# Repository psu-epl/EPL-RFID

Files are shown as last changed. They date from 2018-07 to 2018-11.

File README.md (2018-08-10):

# EPL-RFID
RFID system for controlling access to EPL machines

This repo started as copies of two separate Capstone projects in 2018: the CS
backend Capstone called LUCCA (Lab Usage Controller for Centralized Administration)
and the ECE Capstone called EPL RFID Capstone Project.

Here are links to the previous repos:

### LUCCA:
#### Repo: https://github.com/LUCCA-Capstone/LUCCA
#### Wiki: https://github.com/LUCCA-Capstone/LUCCA/wiki

### EPL RFID:
#### Repo: https://github.com/Crimson89/RFID-Capstone
#### Wiki: https://github.com/Crimson89/RFID-Capstone/wiki

# Building ESP-IDF toolchain and environment
From a linux console type the following commands:   

git clone https://github.com/psu-epl/EPL-RFID.git  
cd EPL-RFID  
git submodule update --init  

Then follow "the Setting Up ESP-IDF" directions here: https://github.com/espressif/esp-idf  

This involves lots of building packages from source. You likely don't want to do this very many times.

make sure you edit your PATH variable in your ~/.bashrc to something similar to:

export IDF_PATH=~/path/to/submodule/esp-idf  
export PATH=$PATH:/home/chad/path/to/binaries/xtensa-esp32-elf/bin:/home/chad/path/to/binaries/crosstool-NG/builds/xtensa-esp32-elf/bin/

Bad things happen when you are following the wrong path...

Focus your chi using "echo $PATH"

Code to victory brave warrior!

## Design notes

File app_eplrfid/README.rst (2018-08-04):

app_eplrfid is based off the ESP-IDF template app.

Happy coding!

ESP-IDF template app
====================

This is a template application to be used with `Espressif IoT Development Framework`_ (ESP-IDF). 

Please check ESP-IDF docs for getting started instructions.

Code in this repository is Copyright (C) 2016 Espressif Systems, licensed under the Apache License 2.0 as described in the file LICENSE.

.. _Espressif IoT Development Framework: https://github.com/espressif/esp-idf

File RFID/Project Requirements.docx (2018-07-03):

ECE Capstone – Multiple Band RFID Scanner and Registration

Product Design Specification

1/1/2018

Capstone Team

Steven Bagdasarians

Julian Saunders

Dawit Amare

Josh Guenther

Background

The Electronics Prototyping Lab (EPL) is a Rapid Manufacturing lab in FAB 84-10. There is a lot of expensive and mildly complicated equipment in the lab. Some people who don’t know how to use the equipment come in and try to use the equipment and then end up either hurting the equipment or wasting time. We would like to be able to use hardware to control access of the equipment using our user database and training database. The overall process of use is: lab user uses their student ID or provided RFID tag to identify themselves and the system then checks a database to confirm they have been trained/checked out on the equipment and then gives some visual/auditory feedback and may deny them access to the equipment by prohibiting it from being powered up.

Functionality:

- Must read two different RFID bands (125 KHz & 13.5 MHz)
- Must communicate with other modules with Wifi
- Must run on embedded Linux environment
- Must incorporate a serial 2x30 LCD display
- Must display user information when badge is scanned
- Must include hdmi out, usb ports, digital pins, sd port
- Must be programmed with ip address, station id, unique id, etc
- Must maintain module identity/information after power down
- Should notify user if they have access or not (beeps, flashes, voice, etc)
- May utilize Bluetooth 3.0/4.0/BLE to communicate along with Wifi
- May have optional/customizable notification settings

Marketing Requirements:

- Must be usable by anyone / straightforward documentation
- Should be inexpensive to make
- Should only require keyboard and monitor to set up
- May be compatible with other databases

Performance:

- Must be easily programed and reprogrammable
- Must be easy to debug (displays ip address, station id, unique device id, etc)
- Should have a quick response time of no more than 1 second

Economic:

- Must be cheaper than commercial products

Energy:

- Must run off USB power (5v Supply)
- Should have protection from power spikes
- My have backup battery power if needed

Manufacturing:

- Must be easily reproduced.
- Must work for Raspberry Pi 0 W
- Must be Modular
- Should have custom designed PCB for final design
- Should have simple and inexpensive casing

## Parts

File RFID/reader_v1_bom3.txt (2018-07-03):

Partlist exported from C:/Users/Owner/Documents/eagle/Capstone_RFID/reader_v1.sch at 5/26/2018 2:22 PM

Qty Value                                 Package     Parts                        Description                                                                                                   
1   Red LED                               LED5MM      RED                          LED                                                                     
1   Green LED                             LED5MM      GREEN                        LED                                                                                                                         
1   1 Meg                                 R0805       R2                           RESISTOR, American symbol                                               
1   1.8k                                  R0805       R3                           RESISTOR, American symbol                                               
1   100                                   R0805       R11                          RESISTOR, American symbol                                               
4   100n                                  C0805       C12, C13, C16, C17           CAPACITOR, European symbol                                              
6   10k                                   R0805       R7, R8, R9, R12, R15, R18    RESISTOR, American symbol                                               
1   12V Zener                             Thru Hole   D1                           DIODE                                                                   
2   15k                                   R0805       R10, R19                     RESISTOR, American symbol                                               
1   16MHz                                 CRYSTAL     Y1                           16MHz Crystal                                                           
1   1N5824 (20-40V, 5A Schottkey)         Thru Hole   D2                           Schottky Diode                                                          
2   1k                                    R0805       R13, R14                     RESISTOR, American symbol                                               
7   1n                                    C0805       C4, C6, C7, C8, C9, C10, C11 CAPACITOR, European symbol                                              
1   2.2n                                  C0805       C5                           CAPACITOR, European symbol                                              
1   2.7k                                  R0805       R5                           RESISTOR, American symbol                                               
2   220                                   R0805       R16, R17                     RESISTOR, American symbol                                               
1   220u                                  Polarized   C20                          POLARIZED CAPACITOR, American symbol                                    
2   22p                                   C0805       C14, C15                     CAPACITOR, European symbol                                              
1   328P                                  DIP28       U1                           Atmel 328P                                                              
1   33u                                   Thru Hole   L1                           INDUCTOR, American symbol                                               
1   47k                                   R0805       R4                           RESISTOR, American symbol                                               
1   680u                                  Polarized   C19                          POLARIZED CAPACITOR, American symbol                                    
1   82k                                   R0805       R6                           RESISTOR, American symbol                                               
1   860k                                  R0805       R1                           RESISTOR, American symbol                                               
1   BUZZER (=<3.3V)                       BUZZER-12MM BUZZER                       Buzzer                                                                  
2   LF353N                                DIL08       LF353_1, LF353_2             OP AMP                                                                  
1   LM2596T                               T05D        LM2596                       SIMPLE SWITCHER® Power Converter 150 kHz 3A Step-Down Voltage Regulator 
1   2x20 Female Header		 	  2X20        J1                           Raspberry Pi GPIO Header

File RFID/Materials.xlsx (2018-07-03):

Date | Part | Quantity | Location | Price/unit | Price (Total) | Notes
2018-01-18 | RPi 3 - 16GB Noobs | 1 | EPL | $50.00 | $50.00
2018-02-02 | 28 Guage Magnetic Wire | Spool | EPL |  | #VALUE!
2018-02-02 | 100 Ohm Resitor | 1 | EPL | $0.10 | $0.10
2018-02-02 | 1.8 nF Cap | 1 | EPL | $0.25 | $0.25
2018-02-22 | MCP3201 (ADC) | 1 | EPL | $3.00 | $3.00
2018-03-08 | LM358 (Op Amp) | 3 | EPL | $0.60 | $1.80
2108-03-28 | Resistors | 13 | EPL | $0.10 | $1.30
2018-03-28 | Capacitors | 6 | EPL | $0.25 | $1.50
2018-04-01 | LF353 (Op Amp) | 5 | EPL | $0.75 | $3.75
2018-04-01 | NE5532 (Op Amp) | 3 | EPL | $1.25 | $3.75
2018-04-19 | LM555 Timer | 2 | EPL | $0.50 | $1.00
2018-04-26 | 74HC74 Dual D Flip Flop | 1 | EPL | $0.50 | $0.50
2018-05-10 | Atmega328P | 2 | EPL | $5.00 | $10.00
2018-05-19 | Copper Board (4x6) Single Sided | 1 | EPL | $4.00 | $4.00
2018-05-19 | SMD Caps | 11 | EPL | $0.10 | $1.10
2018-05-19 | SMD Resistors | 14 | EPL | $0.10 | $1.40
2018-05-20 | USB A to B | 1 | EPL | $3.00 | $3.00
2018-06-06 | USB micro | 1 | EPL | $3.00 | $3.00
2018-06-06 | 2x3 Protoboard | 1 | EPL | $3.00 | $3.00
2018-06-07 | HDMI Cable | 1 | EPL | $5.00 | $5.00
2018-06-07 | 12V 2A Power Supply | 2 | EPL |  | $0.00

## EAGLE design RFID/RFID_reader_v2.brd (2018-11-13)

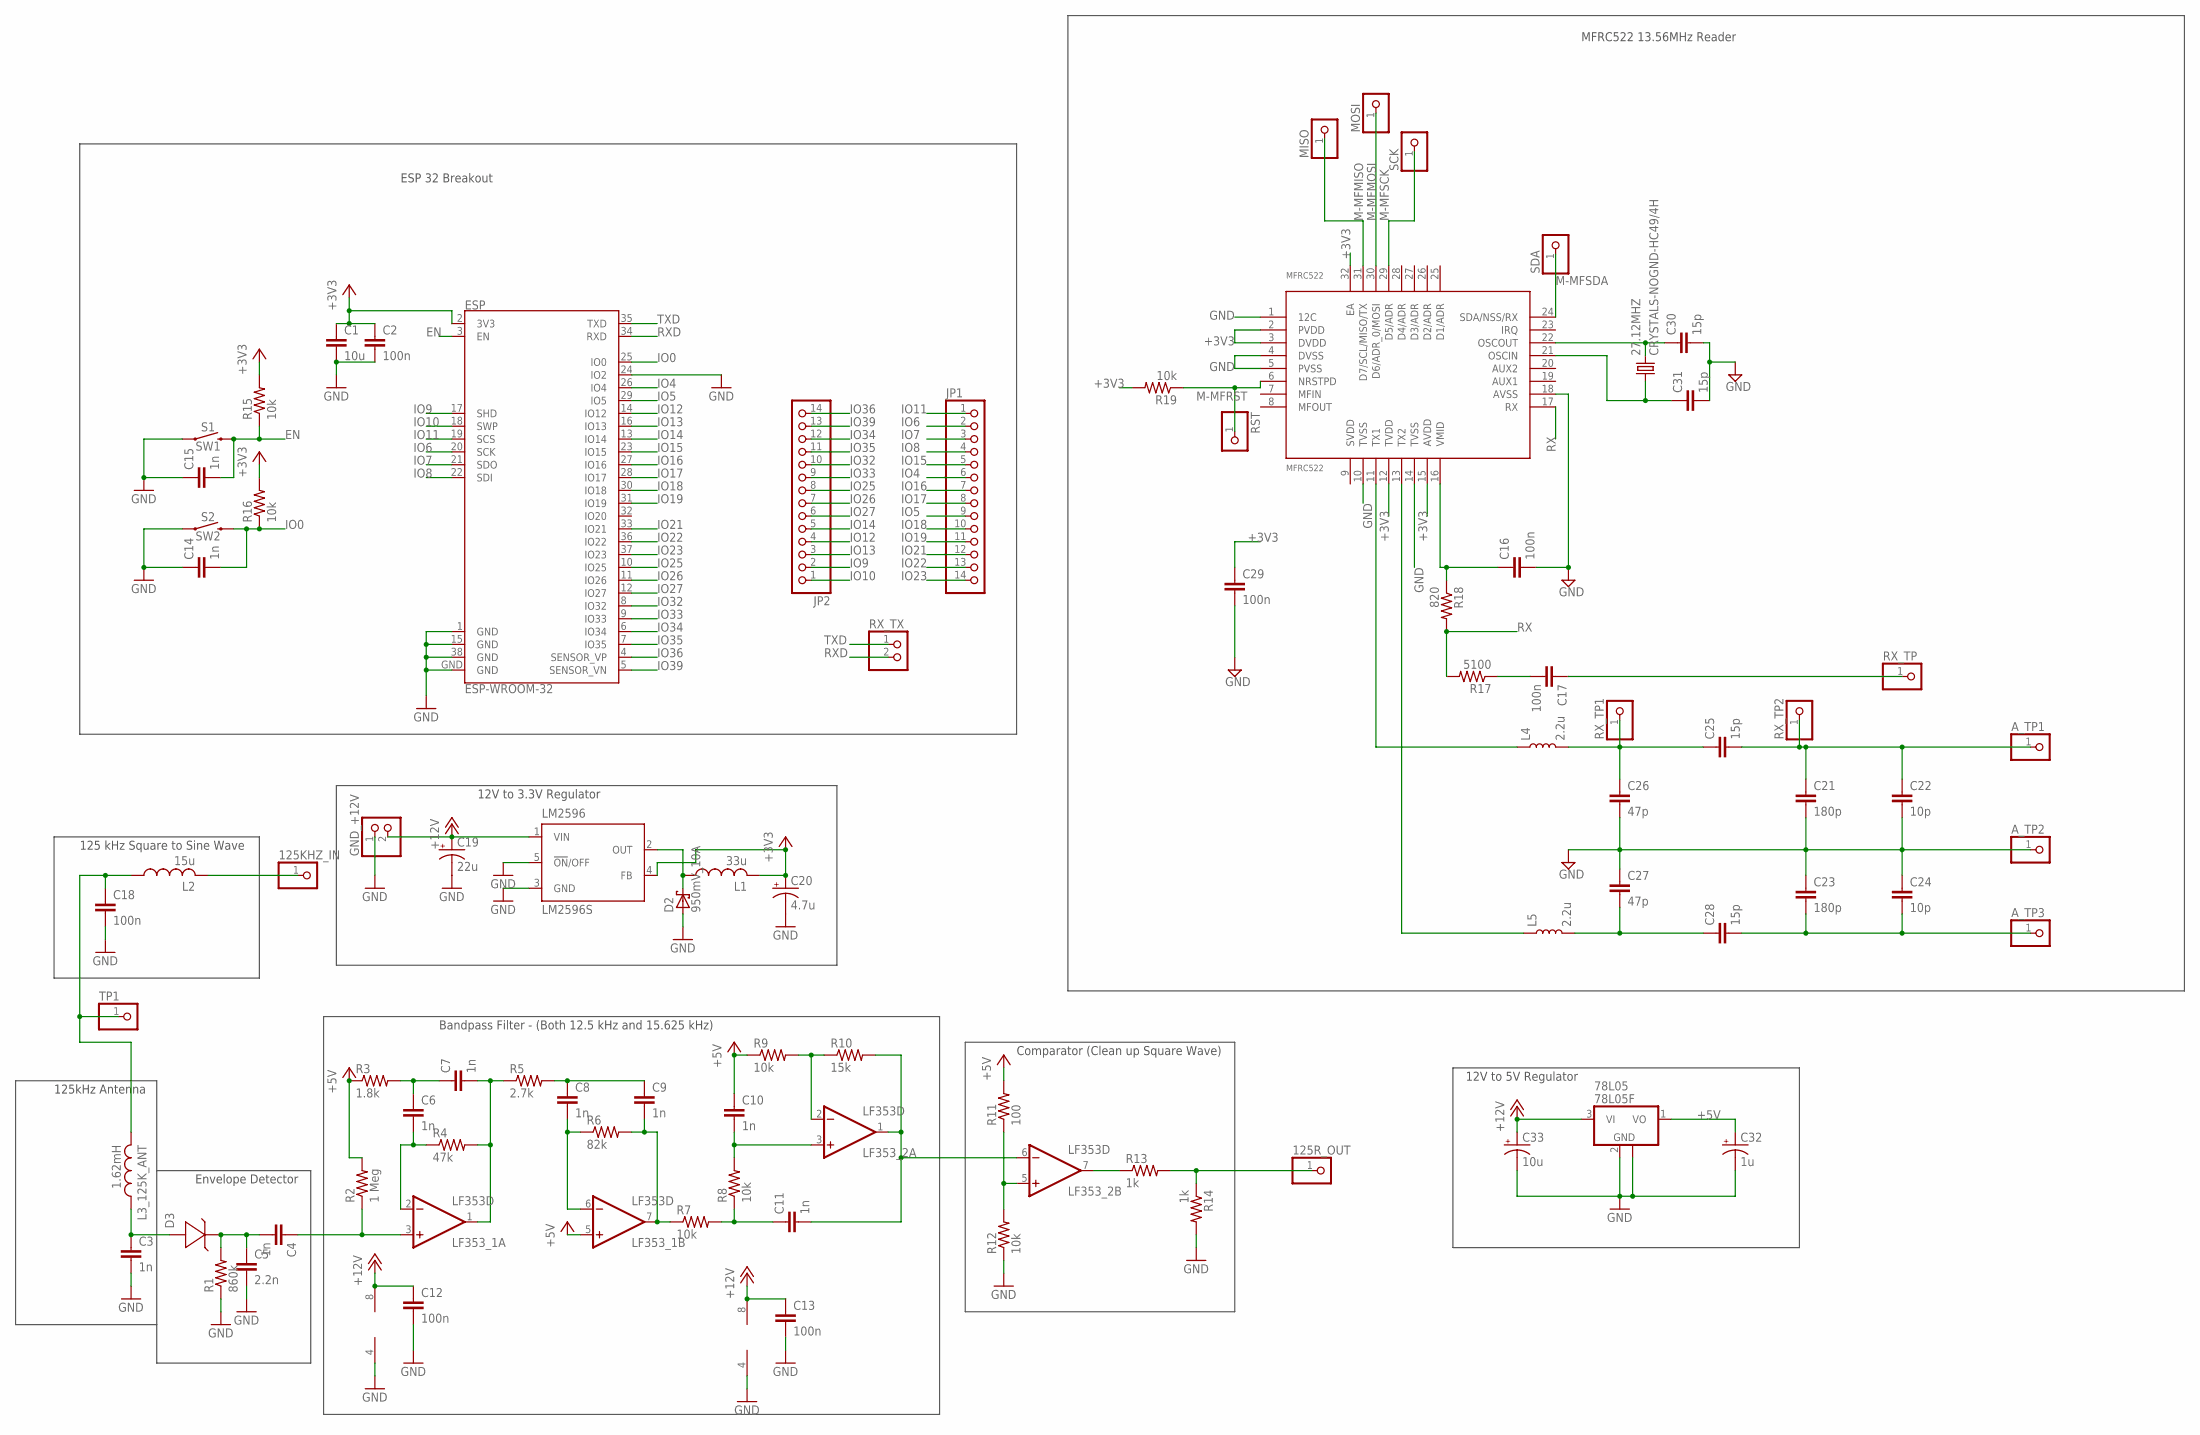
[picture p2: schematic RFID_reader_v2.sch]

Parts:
27.12MHZ: CRYSTALS-NOGND-HC49/4H; HC49
78L05: 78L05F; SOT89
125KHZ_IN, 125R_OUT: PINHD-1X1; 1X01
A_TP1, A_TP2, A_TP3: PINHD-1X1; 1X01
C1: 10u; C0805
C2, C12, C13, C18: 100n; C0805
C3, C4, C6, C7, C8, C9, C10, C11, C14, C15: 1n; C0805
C5: 2.2n; C0805
C16, C17, C29: 100n; C0603
C19: 22u; SANYO-OSCON_SMD_B6
C20: 4.7u; SMC_C
C21, C23: 180p; C0603
C22, C24: 10p; C0603
C25, C28, C30, C31: 15p; C0603
C26, C27: 47p; C0603
C32: 1u; SMC_A
C33: 10u; SMC_C
D2: 950mV_10A; SMC
D3: ZENER; SOD123
ESP: ESP-WROOM-32
GND_+12V: PINHD-1X2; 1X02
JP1, JP2: PINHD-1X14; 1X14
L1: 33u; 0207/10
L2: 15u; L2012C
L3_125K_ANT: 1.62mH; 0207/10
L4, L5: 2.2u; 0603
LF353_1, LF353_2: LF353D; SO08
LM2596: LM2596S; TO263-5
MFRC522: MFRC522; MFR522
MISO: PINHD-1X1; 1X01
MOSI: PINHD-1X1; 1X01
R1: 860k; R0805
R2: 1 Meg; R0805
R3: 1.8k; R0805
R4: 47k; R0805
R5: 2.7k; R0805
R6: 82k; R0805
R7, R8, R9, R12, R15, R16: 10k; R0805
R10: 15k; R0805
R11: 100; R0805
R13, R14: 1k; R0805
R17: 5100; R0603
R18: 820; R0603
R19: 10k; R0603
RST: PINHD-1X1; 1X01
RX_TP, RX_TP1, RX_TP2: PINHD-1X1; 1X01
RX_TX: PINHD-1X2; 1X02
S1: SW1; TACTILE_SWITCH_SMD_6.0X3.5MM
S2: SW2; TACTILE_SWITCH_SMD_6.0X3.5MM
SCK: PINHD-1X1; 1X01
SDA: PINHD-1X1; 1X01
TP1: PINHD-1X1; 1X01

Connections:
+3V3: C1.1, C2.1, C20.+, C29.1, ESP.2 (3V3), L1.2, LM2596.4 (FB), MFRC522.2 (PVDD), MFRC522.3 (DVDD), MFRC522.12 (TVDD), MFRC522.15 (AVDD), MFRC522.32 (EA), R15.2, R16.2, R19.2
+5V: 78L05.1 (VO), C10.1, C32.+, LF353_1.5 (+IN), R2.2, R3.1, R9.1, R11.2
+12V: 78L05.3 (VI), C12.1, C13.1, C19.+, C33.+, GND_+12V.2, LF353_1.8 (V+), LF353_2.8 (V+), LM2596.1 (VIN)
EN: C15.2, ESP.3 (EN), R15.1, S1.2
GND: 78L05.2 (GND), 78L05.2@1 (GND), A_TP2.1, C1.2, C2.2, C3.2, C5.2, C12.2, C13.2, C14.1, C15.1, C16.2, C18.2, C19.-, C20.-, C21.2, C22.2, C23.1, C24.1, C26.2, C27.1, C29.2, C30.2, C31.2, C32.-, C33.-, D2.A, ESP.1 (GND), ESP.15 (GND), ESP.24 (IO2), ESP.38 (GND), ESP.GND, GND_+12V.1, LF353_1.4 (V-), LF353_2.4 (V-), LM2596.3 (GND), LM2596.5 (!ON!/OFF), MFRC522.1 (12C), MFRC522.4 (DVSS), MFRC522.5 (PVSS), MFRC522.10 (TVSS), MFRC522.14 (TVSS), MFRC522.18 (AVSS), R1.1, R12.1, R14.2, S1.1, S2.1
IO0: C14.2, ESP.25 (IO0), R16.1, S2.2
IO4: ESP.26 (IO4), JP1.6
IO5: ESP.29 (IO5), JP1.9
IO6: ESP.20 (SCK), JP1.2
IO7: ESP.21 (SDO), JP1.3
IO8: ESP.22 (SDI), JP1.4
IO9: ESP.17 (SHD), JP2.2
IO10: ESP.18 (SWP), JP2.1
IO11: ESP.19 (SCS), JP1.1
IO12: ESP.14 (IO12), JP2.4
IO13: ESP.16 (IO13), JP2.3
IO14: ESP.13 (IO14), JP2.5
IO15: ESP.23 (IO15), JP1.5
IO16: ESP.27 (IO16), JP1.7
IO17: ESP.28 (IO17), JP1.8
IO18: ESP.30 (IO18), JP1.10
IO19: ESP.31 (IO19), JP1.11
IO21: ESP.33 (IO21), JP1.12
IO22: ESP.36 (IO22), JP1.13
IO23: ESP.37 (IO23), JP1.14
IO25: ESP.10 (IO25), JP2.8
IO26: ESP.11 (IO26), JP2.7
IO27: ESP.12 (IO27), JP2.6
IO32: ESP.8 (IO32), JP2.10
IO33: ESP.9 (IO33), JP2.9
IO34: ESP.6 (IO34), JP2.12
IO35: ESP.7 (IO35), JP2.11
IO36: ESP.4 (SENSOR_VP), JP2.14
IO39: ESP.5 (SENSOR_VN), JP2.13
M-MFMISO: MFRC522.31 (D7/SCL/MISO/TX), MISO.1
M-MFMOSI: MFRC522.30 (D6/ADR_0/MOSI), MOSI.1
M-MFRST: MFRC522.6 (NRSTPD), R19.1, RST.1
M-MFSCK: MFRC522.29 (D5/ADR), SCK.1
M-MFSDA: MFRC522.24 (SDA/NSS/RX), SDA.1
unnamed: C4.2, C5.1, D3.C (-), R1.2
unnamed: C4.1, LF353_1.3 (+IN), R2.1
unnamed: D2.C, L1.1, LM2596.2 (OUT)
unnamed: C3.1, D3.A (+), L3_125K_ANT.1
unnamed: 125KHZ_IN.1, L2.2
unnamed: C6.1, C7.1, R3.2
unnamed: C6.2, LF353_1.2 (-IN), R4.1
unnamed: C8.1, C9.1, R5.2
unnamed: C7.2, LF353_1.1 (OUT), R4.2, R5.1
unnamed: C8.2, LF353_1.6 (-IN), R6.1
unnamed: C9.2, LF353_1.7 (OUT), R6.2, R7.1
unnamed: C11.1, R7.2, R8.1
unnamed: C10.2, LF353_2.3 (+IN), R8.2
unnamed: C17.2, R17.1
unnamed: LF353_2.2 (-IN), R9.2, R10.1
unnamed: C11.2, LF353_2.1 (OUT), LF353_2.6 (-IN), R10.2
unnamed: C18.1, L2.1, L3_125K_ANT.2, TP1.1
unnamed: LF353_2.5 (+IN), R11.1, R12.2
unnamed: LF353_2.7 (OUT), R13.1
unnamed: 125R_OUT.1, R13.2, R14.1
unnamed: C27.2, C28.1, L5.2
unnamed: C25.1, C26.1, L4.2, RX_TP1.1
unnamed: C17.1, RX_TP.1
unnamed: A_TP1.1, C21.1, C22.1, C25.2, RX_TP2.1
unnamed: A_TP3.1, C23.2, C24.2, C28.2
OSCIN: 27.12MHZ.1, C31.1, MFRC522.21 (OSCIN)
OSCOUT: 27.12MHZ.2, C30.1, MFRC522.22 (OSCOUT)
RX: MFRC522.17 (RX), R17.2, R18.2
RXD: ESP.34 (RXD), RX_TX.2
TX1: L4.1, MFRC522.11 (TX1)
TX2: L5.1, MFRC522.13 (TX2)
TXD: ESP.35 (TXD), RX_TX.1
VMID: C16.1, MFRC522.16 (VMID), R18.1

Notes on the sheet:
Envelope Detector
Bandpass Filter - (Both 12.5 kHz and 15.625 kHz)
Comparator (Clean up Square Wave)
125kHz Antenna
125 kHz Square to Sine Wave
12V to 5V Regulator
12V to 3.3V Regulator
ESP 32 Breakout
MFRC522 13.56MHz Reader

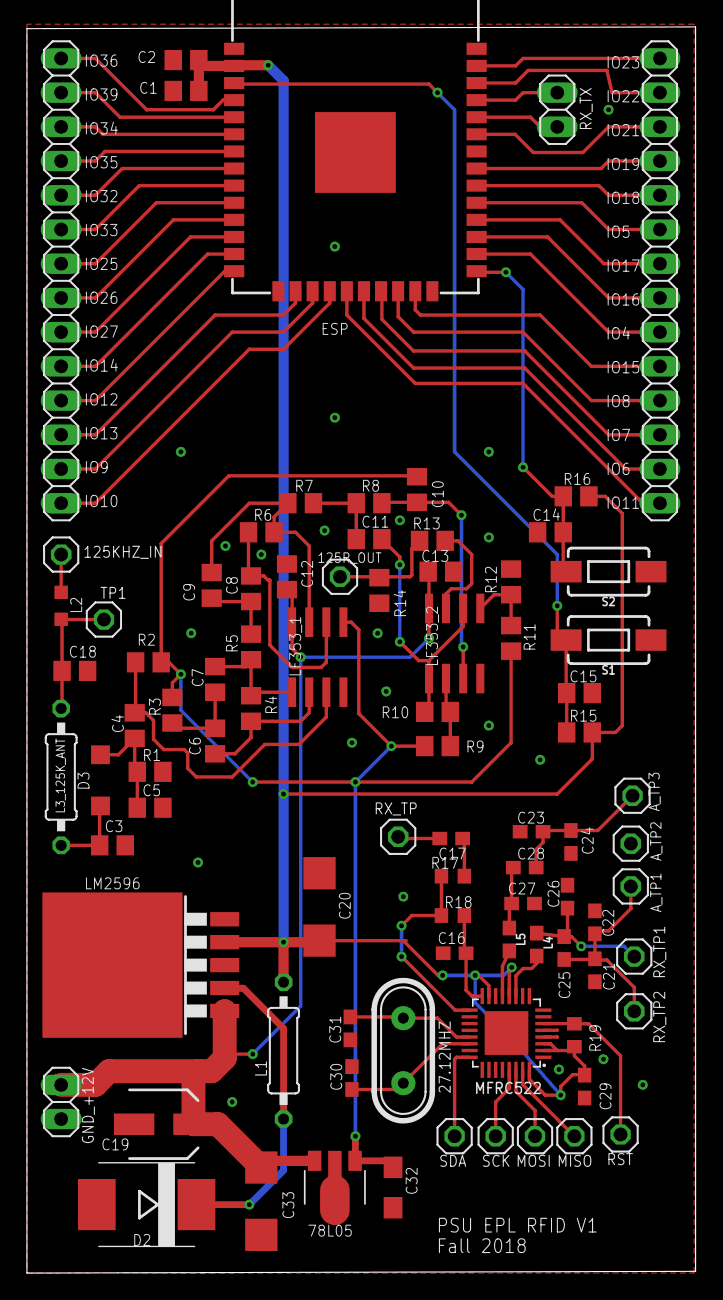
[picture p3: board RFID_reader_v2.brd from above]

Board: 2 copper layers, 49.6 x 92.5 mm, 86 parts (0 on the bottom side), 72 nets.

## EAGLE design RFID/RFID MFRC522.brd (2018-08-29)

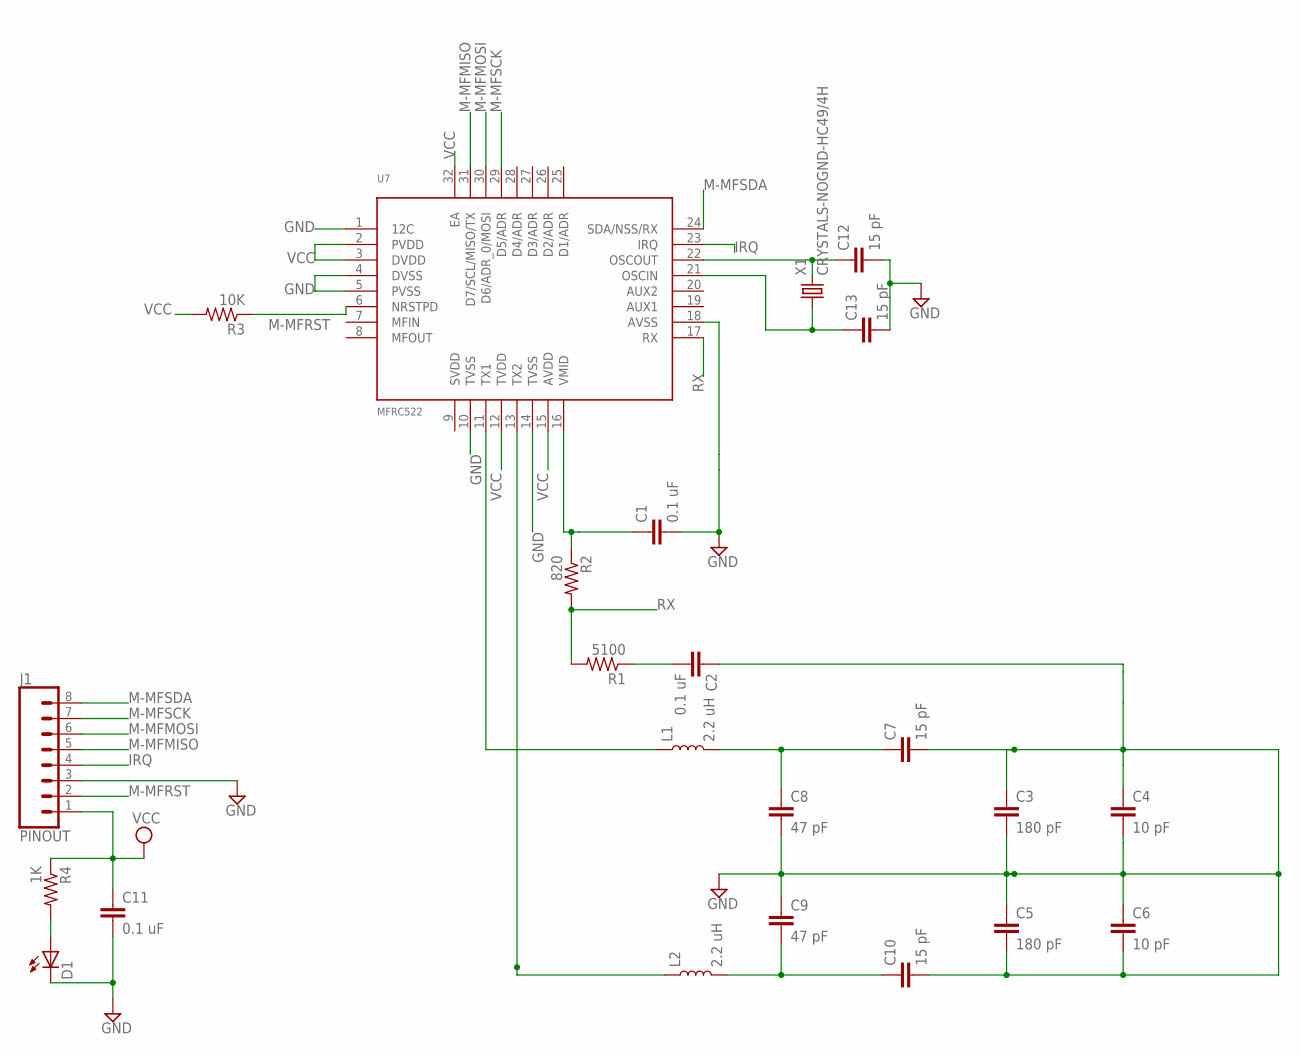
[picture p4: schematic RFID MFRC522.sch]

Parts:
C1, C2, C11: 0.1 uF; C0603
C3, C5: 180 pF; C0603
C4, C6: 10 pF; C0603
C7, C10, C12, C13: 15 pF; C0603
C8, C9: 47 pF; C0603
D1: LED; C1210
J1: PINOUT; 1X08_NO_SILK
L1, L2: 2.2 uH; 0603
R1: 5100; R0603
R2: 820; R0603
R3: 10K; R0603
R4: 1K; R0603
U7: MFRC522; MFR522
X1: CRYSTALS-NOGND-HC49/4H; HC49

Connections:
GND: C1.2, C2.1, C3.1, C3.2, C4.1, C4.2, C5.1, C5.2, C6.1, C6.2, C7.2, C8.2, C9.1, C10.2, C11.2, C12.2, C13.2, D1.C, J1.3, U7.1 (12C), U7.4 (DVSS), U7.5 (PVSS), U7.10 (TVSS), U7.14 (TVSS), U7.18 (AVSS)
IRQ: J1.4, U7.23 (IRQ)
M-MFMISO: J1.5, U7.31 (D7/SCL/MISO/TX)
M-MFMOSI: J1.6, U7.30 (D6/ADR_0/MOSI)
M-MFRST: J1.2, R3.1, U7.6 (NRSTPD)
M-MFSCK: J1.7, U7.29 (D5/ADR)
M-MFSDA: J1.8, U7.24 (SDA/NSS/RX)
unnamed: D1.A, R4.2
unnamed: C2.2, R1.1
unnamed: C9.2, C10.1, L2.2
unnamed: C7.1, C8.1, L1.2
OSCIN: C13.1, U7.21 (OSCIN), X1.1
OSCOUT: C12.1, U7.22 (OSCOUT), X1.2
RX: R1.2, R2.2, U7.17 (RX)
TX1: L1.1, U7.11 (TX1)
TX2: L2.1, U7.13 (TX2)
VCC: C11.1, J1.1, R3.2, R4.1, U7.2 (PVDD), U7.3 (DVDD), U7.12 (TVDD), U7.15 (AVDD), U7.32 (EA)
VMID: C1.1, R2.1, U7.16 (VMID)

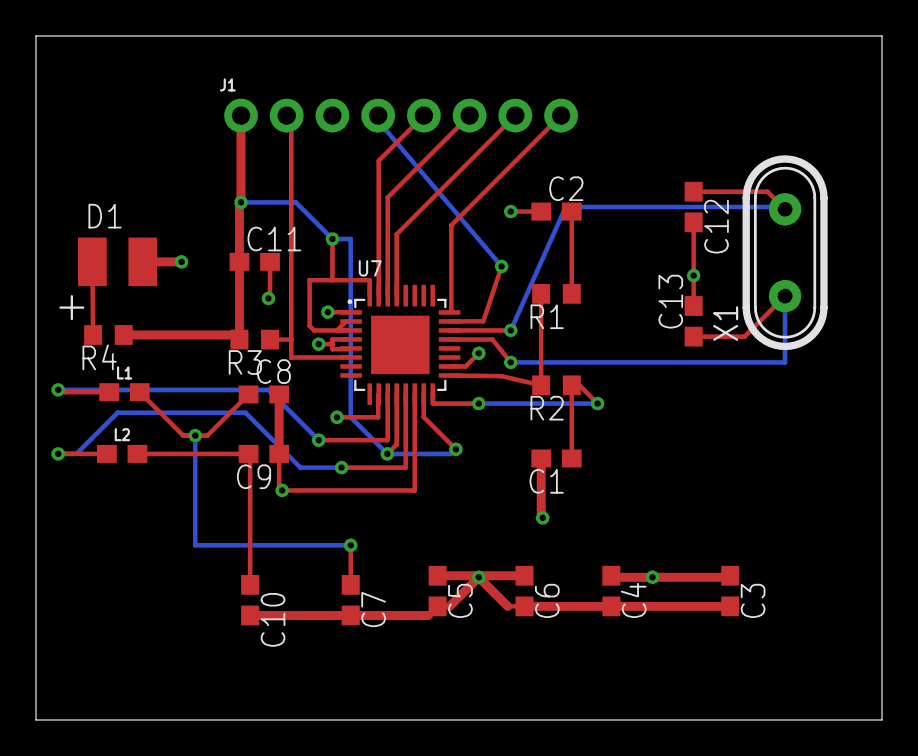
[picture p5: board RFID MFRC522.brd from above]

Board: 2 copper layers, 47.0 x 38.0 mm, 23 parts (0 on the bottom side), 18 nets.

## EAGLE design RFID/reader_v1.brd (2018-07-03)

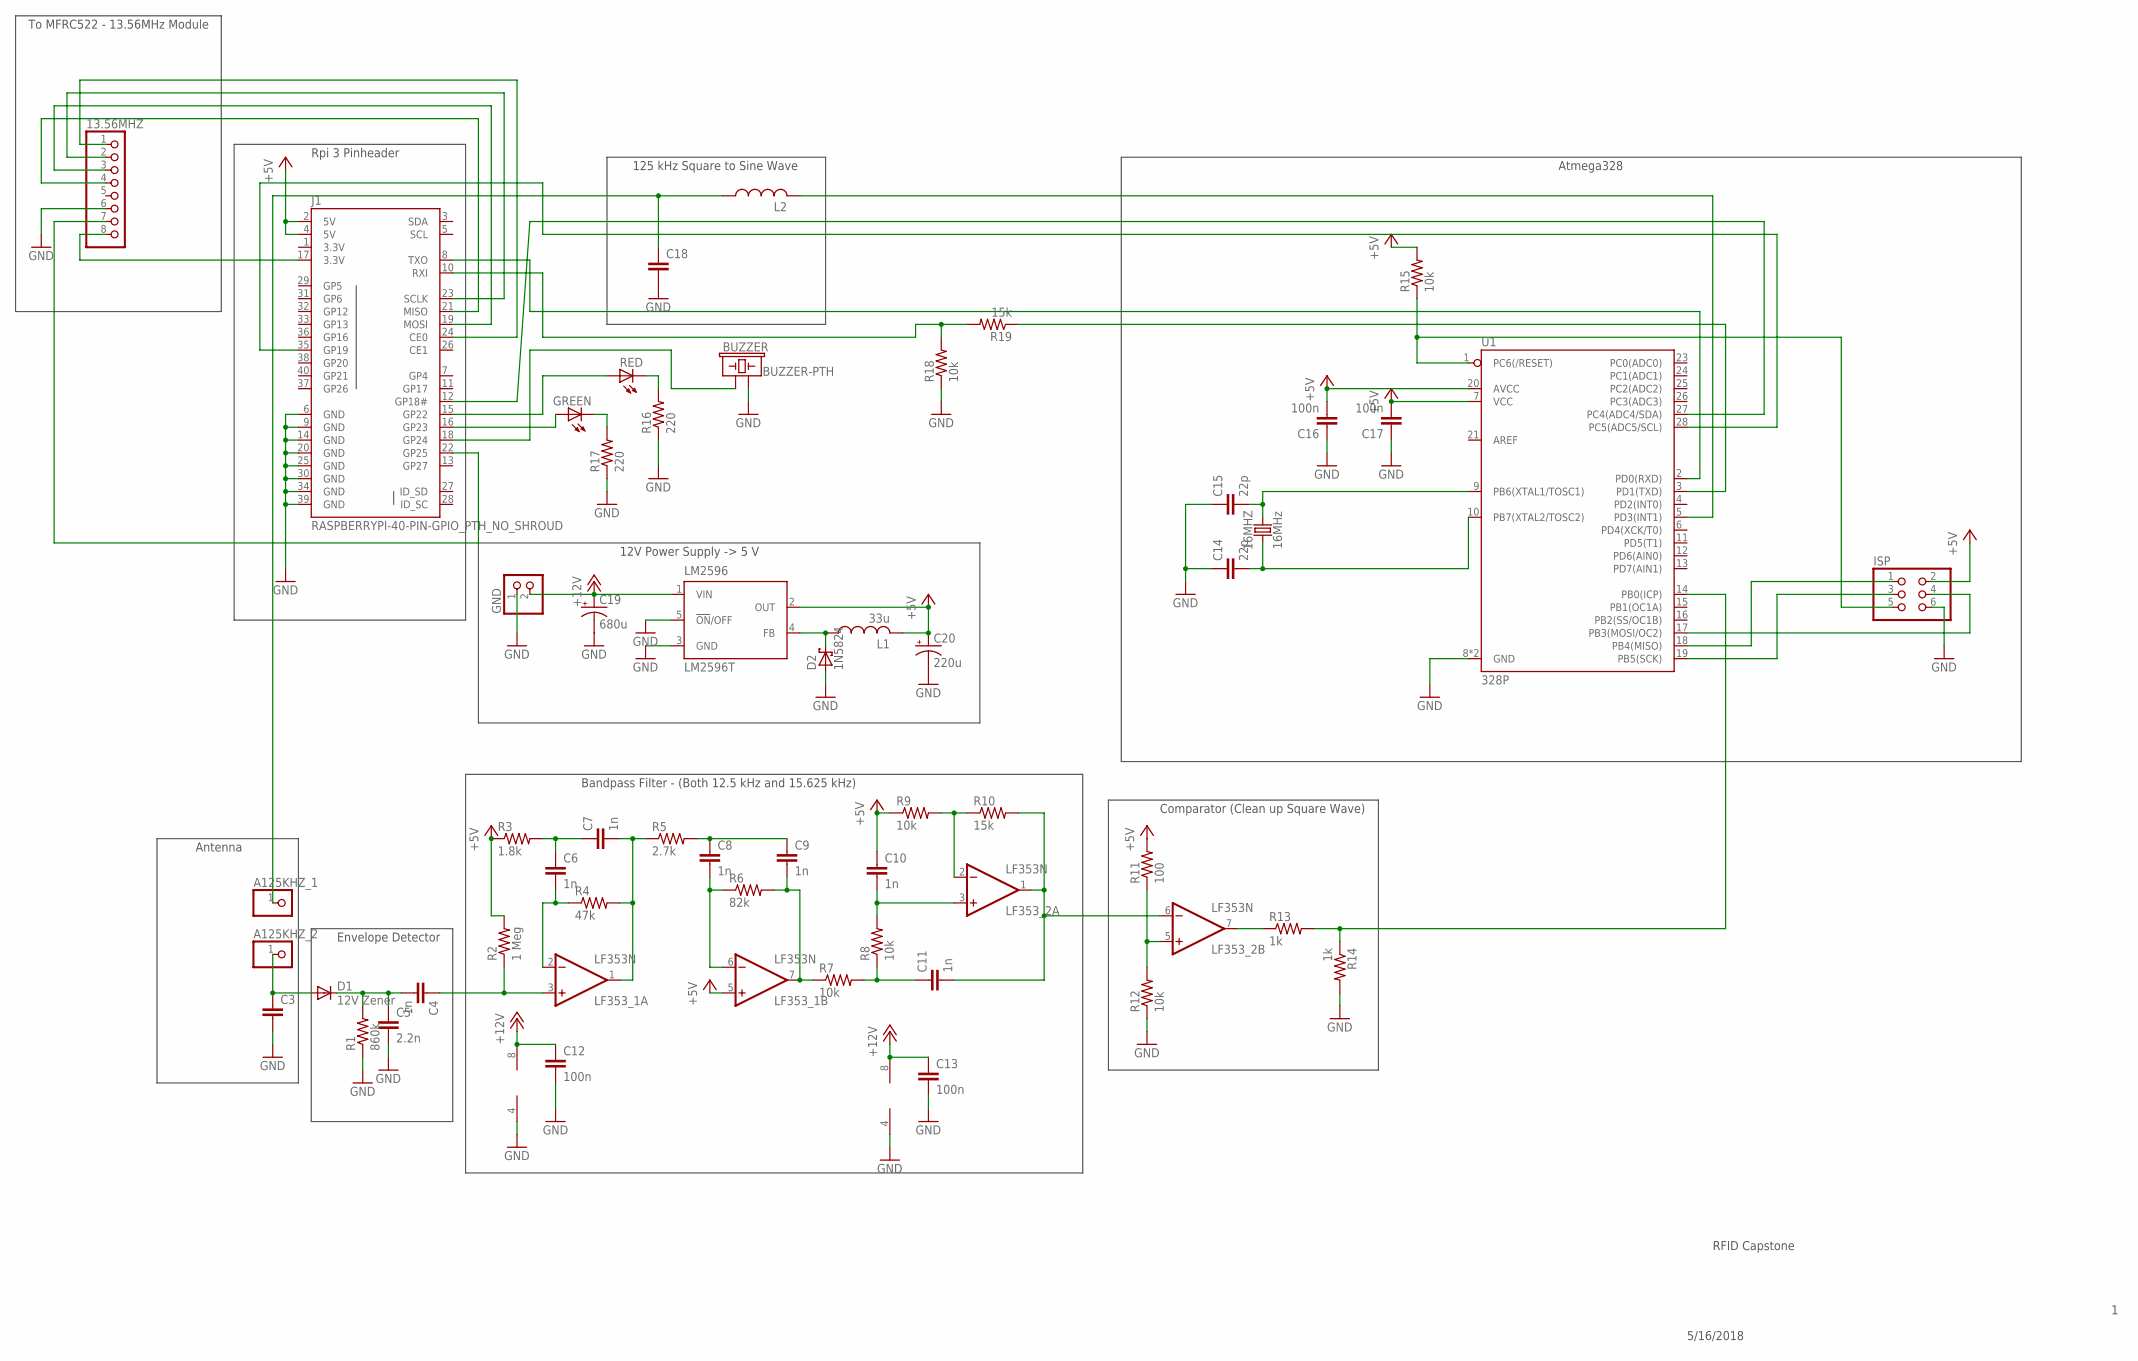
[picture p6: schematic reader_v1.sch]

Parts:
13.56MHZ: PINHD-1X8; 1X08
16MHZ: 16MHz; HC49US
A125KHZ_1, A125KHZ_2: PINHD-1X1; 1X01
BUZZER: BUZZER-PTH; BUZZER-12MM
C3, C18: C-EUC0805; C0805
C4, C6, C7, C8, C9, C10, C11: 1n; C0805
C5: 2.2n; C0805
C12, C13, C16, C17: 100n; C0805
C14, C15: 22p; C0805
C19: 680u; E3,5-8
C20: 220u; E2-5
D1: 12V Zener; DO35-7
D2: 1N5824; DO35-7
GND: PINHD-1X2; 1X02
GREEN: LED5MM
ISP: PINHD-2X3; 2X03
J1: RASPBERRYPI-40-PIN-GPIO_PTH_NO_SHROUD; 2X20
L1: 33u; 0207/10
L2: L-US0207/10; 0207/10
LF353_1, LF353_2: LF353N; DIL08
LM2596: LM2596T; T05D
R1: 860k; R0805
R2: 1 Meg; R0805
R3: 1.8k; R0805
R4: 47k; R0805
R5: 2.7k; R0805
R6: 82k; R0805
R7, R8, R9, R12, R15, R18: 10k; R0805
R10, R19: 15k; R0805
R11: 100; R0805
R13, R14: 1k; R0805
R16, R17: 220; R0805
RED: LED5MM
U1: 328P; DIP28

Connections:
3.3V: J1.1 (3.3V)
+5V: C10.1, C16.2, C17.2, C20.+, ISP.2, J1.2 (5V), J1.4 (5V), L1.2, LF353_1.5 (+IN), LM2596.2 (OUT), R2.2, R3.1, R9.1, R11.2, R15.2, U1.7 (VCC), U1.20 (AVCC)
+12V: C12.1, C13.1, C19.+, GND.2, LF353_1.8 (V+), LF353_2.8 (V+), LM2596.1 (VIN)
GND: 13.56MHZ.6, BUZZER.- (2), C3.2, C5.2, C12.2, C13.2, C14.1, C15.1, C16.1, C17.1, C18.2, C19.-, C20.-, D2.A, GND.1, ISP.6, J1.6 (GND), J1.9 (GND), J1.14 (GND), J1.20 (GND), J1.25 (GND), J1.30 (GND), J1.34 (GND), J1.39 (GND), LF353_1.4 (V-), LF353_2.4 (V-), LM2596.3 (GND), LM2596.5 (!ON!/OFF), R1.1, R12.1, R14.2, R16.1, R17.1, R18.1, U1.8 (GND), U1.22 (GND)
unnamed: C4.2, C5.1, D1.C, R1.2
unnamed: C4.1, LF353_1.3 (+IN), R2.1
unnamed: D2.C, L1.1, LM2596.4 (FB)
unnamed: A125KHZ_2.1, C3.1, D1.A
unnamed: ISP.1, U1.18 (PB4(MISO))
unnamed: C6.1, C7.1, R3.2
unnamed: C6.2, LF353_1.2 (-IN), R4.1
unnamed: C8.1, C9.1, R5.2
unnamed: C7.2, LF353_1.1 (OUT), R4.2, R5.1
unnamed: C8.2, LF353_1.6 (-IN), R6.1
unnamed: C9.2, LF353_1.7 (OUT), R6.2, R7.1
unnamed: C11.1, R7.2, R8.1
unnamed: C10.2, LF353_2.3 (+IN), R8.2
unnamed: 16MHZ.1, C14.2, U1.10 (PB7(XTAL2/TOSC2))
unnamed: LF353_2.2 (-IN), R9.2, R10.1
unnamed: C11.2, LF353_2.1 (OUT), LF353_2.6 (-IN), R10.2
unnamed: 16MHZ.2, C15.2, U1.9 (PB6(XTAL1/TOSC1))
unnamed: LF353_2.5 (+IN), R11.1, R12.2
unnamed: LF353_2.7 (OUT), R13.1
unnamed: R13.2, R14.1, U1.14 (PB0(ICP))
unnamed: ISP.5, R15.1, U1.1 (PC6(/RESET))
unnamed: ISP.3, U1.19 (PB5(SCK))
unnamed: ISP.4, U1.17 (PB3(MOSI/OC2))
unnamed: A125KHZ_1.1, C18.1, L2.1
unnamed: 13.56MHZ.8, J1.17 (3.3V)
unnamed: J1.12 (GP18#), U1.27 (PC4(ADC4/SDA))
unnamed: J1.35 (GP19), U1.28 (PC5(ADC5/SCL))
unnamed: L2.2, U1.5 (PD3(INT1))
unnamed: 13.56MHZ.7, J1.22 (GP25)
unnamed: R16.2, RED.K (C)
unnamed: 13.56MHZ.4, J1.21 (MISO)
unnamed: 13.56MHZ.3, J1.19 (MOSI)
unnamed: 13.56MHZ.2, J1.23 (SCLK)
unnamed: 13.56MHZ.1, J1.24 (CE0)
unnamed: GREEN.K (C), R17.2
unnamed: GREEN.A, J1.16 (GP23)
unnamed: J1.15 (GP22), RED.A
unnamed: BUZZER.+ (1), J1.18 (GP24)
unnamed: J1.10 (RXI), R18.2, R19.2
unnamed: R19.1, U1.3 (PD1(TXD))
unnamed: J1.8 (TXO), U1.2 (PD0(RXD))

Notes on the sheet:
RFID Capstone
5/16/2018
12V Power Supply -> 5 V
Envelope Detector
Bandpass Filter - (Both 12.5 kHz and 15.625 kHz)
Comparator (Clean up Square Wave)
Antenna
To MFRC522 - 13.56MHz Module
Atmega328
125 kHz Square to Sine Wave
Rpi 3 Pinheader

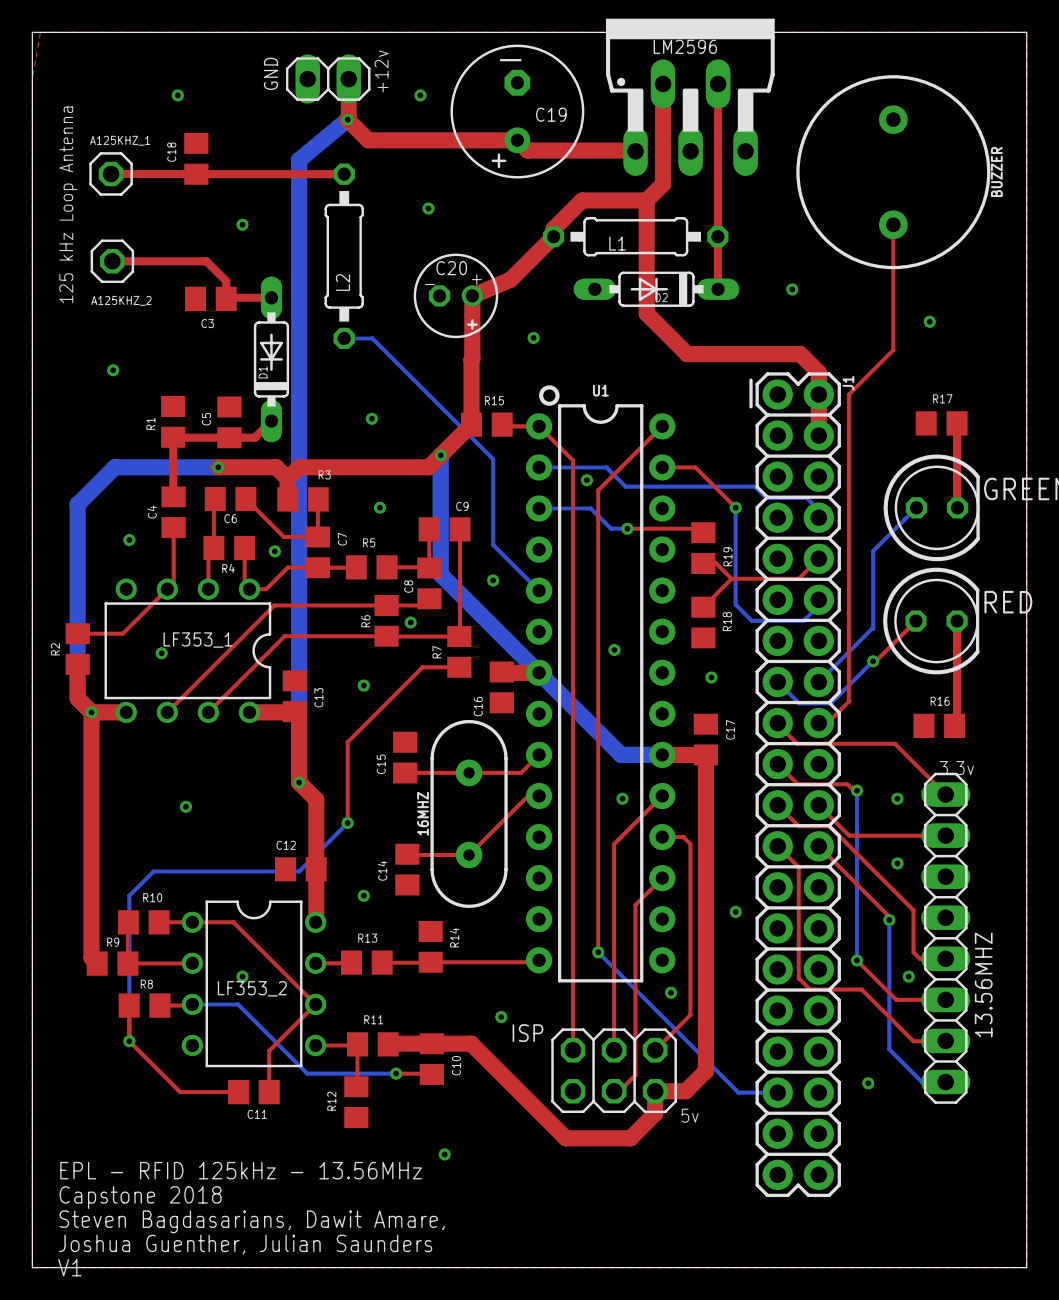
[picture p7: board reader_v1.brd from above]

Board: 2 copper layers, 61.5 x 76.4 mm, 55 parts (0 on the bottom side), 44 nets.

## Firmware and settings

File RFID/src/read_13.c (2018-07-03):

//#include <wiringPi.h>

char VERSION[] = "1.65.3";
#include "main.h"
#include <memory.h>
#define SIZE 200

//#define LED 0
// command line options
uint8_t debug=0;			// trigger for debug messages
int	NoColor = 0;		// disables color output (if set)
int UpdateTrailer = 0;	// if set, will allow to update access permission trailer
int use_vblock= 0xff;	// block if provided (e.g. on command line)

// initialize values
uint8_t use_gpio=0;         // was valid GPIO for reset ?
uint8_t gpio=255;           // GPIO for hard-reset
uint8_t loop = 10, NotEndless = 0; // main loop
uint32_t spi_speed = 1000L; // speed for SP (4 < >125) overruled by config file value
char  fmem_path[255];     // to hold the directory for memory save (from config file)
char  save_mem=0;         // trigger (or disable if issues in config file) to save card info

// card information (globally used)
uint8_t SN[10];             // UID / serial number of card
uint16_t CType=0;           // card type/ ATAQ response
uint8_t SN_len=0;           // length of UID / serial  number ( 4 / 7 / 10)

uint8_t SAK[3];				// SAK (select acknowledgement)
int max_blocks=64;    	// # of block on a card (default is classic = 64)
uint8_t page_step=0;        // increment to read the card

char card_str[25];

struct string {
  char *ptr;
  size_t len;
};

int init_13()
{
  uint8_t gpio=255;           // GPIO for hard-reset
  uint32_t spi_speed = 1000L; // speed for SP (4 < >125) overruled by config file value

  // must be run as root to open /dev/mem in BMC2835
  if (getuid() != 0)
  {
      p_printf(RED, "Must be run as root.\n");
      exit(1);
  }

  Led_On();

  // catch signals
  set_signals();

  /* read /etc/rc522.conf */
  if (get_config_file()) exit(1);

  /* set BCM2835 Pins correct */
  if (HW_init(spi_speed,gpio)) close_out(1);

  /* initialise the RC522 */
  InitRc522();

  /* read & set GID and UID from config file */
  if (read_conf_uid()!= 0) close_out(1);

  digitalWrite(3, 0);

}

int Led_On()
{
  if(wiringPiSetup() == -1)
  {
	  printf("setup wiringPi failed !\n");
	  return -1;
  }
  printf("LED On\n");
  pinMode(3, OUTPUT);
  pinMode(4, OUTPUT);
	digitalWrite(3, HIGH);
	digitalWrite(4, HIGH);
  bcm2835_delay(500);
	digitalWrite(3, LOW);
	digitalWrite(4, LOW);
  bcm2835_delay(500);
  return 0;
}

/* Display in color
 * @param format : Message to display and optional arguments
 *                same as printf
 * @param level :  1 = RED, 2 = GREEN, 3 = YELLOW 4 = BLUE 5 = WHITE
 *
 *  if NoColor was set, output is always WHITE.
 */
void p_printf (int level, char *format, ...)
{
  char* col;
  int	coll=level;
  va_list arg;

  //allocate memory
  col = malloc(strlen(format) + 20);

  if (NoColor) coll = WHITE;

  switch(coll)
  {
	case RED:
		sprintf(col,REDSTR, format);
		break;
	case GREEN:
		sprintf(col,GRNSTR, format);
		break;
	case YELLOW:
		sprintf(col,YLWSTR, format);
		break;
	case BLUE:
		sprintf(col,BLUSTR, format);
		break;
	default:
		sprintf(col,"%s",format);
  }

  va_start (arg, format);
	vfprintf (stdout, col, arg);
	va_end (arg);

	fflush(stdout);

  // release memory
  free(col);
}


/* perform init BCM and GPIO */
uint8_t HW_init(uint32_t spi_speed, uint8_t gpio)
{
  if (!bcm2835_init())
  {
    p_printf(RED,"Can not initialise for BCM2835 access\n");
    exit(1);
  }

  // HARD reset RC522 (only with valid gpio from config)
  if (use_gpio)
  {
    bcm2835_gpio_fsel(gpio, BCM2835_GPIO_FSEL_OUTP);

    // NRSTPD = low is OUT/ power down (PD)]
    bcm2835_gpio_write(gpio, LOW);
    bcm2835_delay(500);

    // NRSTPD = positve edge is reset + run
    bcm2835_gpio_write(gpio, HIGH);
    bcm2835_delay(500);
  }
  else
  {
	  p_printf(RED,"GPIO in config file must be lower than 28\n");
	  exit(1);
  }

  bcm2835_spi_begin();    // set pins 19, 21, 23, 24, 26

  // most significant bit is sent first
  bcm2835_spi_setBitOrder(BCM2835_SPI_BIT_ORDER_MSBFIRST);

  bcm2835_spi_setDataMode(BCM2835_SPI_MODE0);                   // The default

  bcm2835_spi_setClockDivider((uint16_t)(250000L/spi_speed));	  // set speed
  bcm2835_spi_chipSelect(BCM2835_SPI_CS0);                      // using SPI0
  bcm2835_spi_setChipSelectPolarity(BCM2835_SPI_CS0, LOW);      //
  return(0);
}

/* reset and terminate program */
void close_out(int ex_code)
{
  if (use_gpio) bcm2835_gpio_write(gpio, LOW); // set reset
  bcm2835_spi_end();
  bcm2835_close();
  close_config_file();
  exit(ex_code);
}

void usage(char * str)
{
  p_printf(GREEN,"Will only handle MIFARE Crypto-1 (Classic or plus cards)\n\n");

  p_printf(YELLOW, "Usage:\n%s [options]:           (version %s)\n"
  "\t  -a  perform action based on content specific block\n"
  "\t  -b  blocknumber to use, instead of asked by the program\n"
  "\t  -c  change access rights for specific block\n"
  "\t  -d  enable debug mode\n"
  "\t  -e  extra delay between card-access calls for slow cards\n"
  "\t  -h  this help text\n"
  "\t  -k  change authentication key on a specific sector\n"
  "\t  -n  no color in messages\n"
  "\t  -p  perform action on card number (specified in configuration file)\n"
  "\t  -r  read a card block\n"
  "\t  -s  save content all card blocks in a file\n"
  "\t  -t  combined with '-c' allows update trailer access rights\n"
  "\t      (USE WITH CARE AND ONLY IF YOU REALLY KNOW WHAT YOU ARE DOING)\n"
  "\t  -w  write to card block\n",str,VERSION);

  p_printf(GREEN,"\nFOLLOWING IS FOR VALUE BLOCK HANDLING ONLY:\n");

  p_printf(YELLOW,
	"\t  -C  Create a value block\n"
	"\t  -D  Decrement a value block\n"
	"\t  -I  Increment a value block\n"
	"\t  -R  Remove a value block\n"
	"\t  -S  Show a value block\n"
	"\t  -V#  Value to use with value block\n");

	p_printf(GREEN,"\nFOLLOWING IS FOR WRITE & READ FROM COMMAND LINE ONLY:\n");

	p_printf(YELLOW,
	"\t  -N# Starting Sector (default = 1)\n"
	"\t  -B# Starting block (default = 0)\n"
	"\t      OR\n"
	"\t  -A# Starting address (default = 4)\n\n"
	"\t  -M  Message with characters to write\n"
	"\t      OR\n"
	"\t  -H  Message with Hex-bytes to write\n\n"
	"\t      OR\n"
	"\t  -G# Get bytes from the starting point, display as hex characters\n"
	"\t  -T# same as -G, but display as (readable) characters\n");
}

/* calculate the access bits for a block
 * access: block number
 * buff  : trailer information from the card
 *
 * format as specified in the datasheet:
 *
 * C1 C2 C3 (be aware C3 = bit 0 !!!)
 *
 * return code:
 * OK :    block access bits (0 -7)
 * error : 0xff
 */
int calc_access_bits(int access, uint8_t *buff)
{
	int	tmp;
							// offset  -------------- access bits --------------------
                               // C1                      C2                           C3
  if (access == 0)         tmp = (buff[7] & B0B7C1) >> 2 |(buff[8] & B0B8C2) << 1 |(buff[8] & B0B8C3) >> 4;
  else if (access == 1)    tmp = (buff[7] & B1B7C1) >> 3 |(buff[8] & B1B8C2)      |(buff[8] & B1B8C3) >> 5;
  else if (access == 2)    tmp = (buff[7] & B2B7C1) >> 4 |(buff[8] & B2B8C2) >> 1 |(buff[8] & B2B8C3) >> 6;
  else if (access == 3) 	 tmp = (buff[7] & TB7C1)  >> 5 |(buff[8] & TB8C2)  >> 2 |(buff[8] & TB8C3 ) >> 7;
  else tmp = 0xff;

  return(tmp);
}

/* set the access bit for a block
 * ch : choice 0 - 7 (0x30 - 0x37)
 * block : block number to set ( 0 - 3 )
 * buff : pointer to trailer content as read before
 *
 * returns the updated access bits in the buff.
 *
 * format as specified in the datasheet:
 * C1 C2 C3 (be aware C3 = bit 0 !!!)
 */
void set_access_bits(char ch, int block, uint8_t *buff)
{
  switch(ch)     // update Byte 7 & 8
  {
    case 0x30:
      if (block == 0) {
          buff[7] = buff[7] & ~B0B7C1;
          buff[8] = buff[8] & ~B0B8C2;
          buff[8] = buff[8] & ~B0B8C3;
      }
      else if (block == 1){
          buff[7] = buff[7] & ~B1B7C1;
          buff[8] = buff[8] & ~B1B8C2;
          buff[8] = buff[8] & ~B1B8C3;
      }
      else if (block == 2){
          buff[7] = buff[7] & ~B2B7C1;
          buff[8] = buff[8] & ~B2B8C2;
          buff[8] = buff[8] & ~B2B8C3;
      }
      else if (block == 3){
          buff[7] = buff[7] & ~TB7C1;
          buff[8] = buff[8] & ~TB8C2;
          buff[8] = buff[8] & ~TB8C3;
      }
      break;
    case 0x31:
      if (block == 0) {
          buff[7] = buff[7] & ~B0B7C1;
          buff[8] = buff[8] & ~B0B8C2;
          buff[8] = buff[8] |  B0B8C3;
      }
      else if (block == 1){
          buff[7] = buff[7] & ~B1B7C1;
          buff[8] = buff[8] & ~B1B8C2;
          buff[8] = buff[8] |  B1B8C3;
      }
      else if (block == 2){
          buff[7] = buff[7] & ~B2B7C1;
          buff[8] = buff[8] & ~B2B8C2;
          buff[8] = buff[8] |  B2B8C3;
      }
      else if (block == 3){
          buff[7] = buff[7] & ~TB7C1;
          buff[8] = buff[8] & ~TB8C2;
          buff[8] = buff[8] |  TB8C3;
      }
      break;
    case 0x32:
      if (block == 0) {
          buff[7] = buff[7] & ~B0B7C1;
          buff[8] = buff[8] |  B0B8C2;
          buff[8] = buff[8] & ~B0B8C3;
      }
      else if (block == 1){
          buff[7] = buff[7] & ~B1B7C1;
          buff[8] = buff[8] |  B1B8C2;
          buff[8] = buff[8] & ~B1B8C3;
      }
      else if (block == 2){
          buff[7] = buff[7] & ~B2B7C1;
          buff[8] = buff[8] |  B2B8C2;
          buff[8] = buff[8] & ~B2B8C3;
      }
      else if (block == 3){
          buff[7] = buff[7] & ~TB7C1;
          buff[8] = buff[8] |  TB8C2;
          buff[8] = buff[8] & ~TB8C3;
      }
      break;
    case 0x33:
      if (block == 0) {
          buff[7] = buff[7] & ~B0B7C1;
          buff[8] = buff[8] |  B0B8C2;
          buff[8] = buff[8] |  B0B8C3;
      }
      else if (block == 1){
          buff[7] = buff[7] & ~B1B7C1;
          buff[8] = buff[8] |  B1B8C2;
          buff[8] = buff[8] |  B1B8C3;
      }
      else if (block == 2){
          buff[7] = buff[7] & ~B2B7C1;
          buff[8] = buff[8] |  B2B8C2;
          buff[8] = buff[8] |  B2B8C3;
      }
      else if (block == 3){
          buff[7] = buff[7] & ~TB7C1;
          buff[8] = buff[8] |  TB8C2;
          buff[8] = buff[8] |  TB8C3;
      }
      break;
    case 0x34:
      if (block == 0) {
          buff[7] = buff[7] |  B0B7C1;
          buff[8] = buff[8] & ~B0B8C2;
          buff[8] = buff[8] & ~B0B8C3;
      }
      else if (block == 1){
          buff[7] = buff[7] |  B1B7C1;
          buff[8] = buff[8] & ~B1B8C2;
          buff[8] = buff[8] & ~B1B8C3;
      }
      else if (block == 2){
          buff[7] = buff[7] |  B2B7C1;
          buff[8] = buff[8] & ~B2B8C2;
          buff[8] = buff[8] & ~B2B8C3;
      }
      else if (block == 3){
          buff[7] = buff[7] |  TB7C1;
          buff[8] = buff[8] & ~TB8C2;
          buff[8] = buff[8] & ~TB8C3;
      }
      break;
    case 0x35:
      if (block == 0) {
          buff[7] = buff[7] |  B0B7C1;
          buff[8] = buff[8] & ~B0B8C2;
          buff[8] = buff[8] |  B0B8C3;
      }
      else if (block == 1){
          buff[7] = buff[7] |  B1B7C1;
          buff[8] = buff[8] & ~B1B8C2;
          buff[8] = buff[8] |  B1B8C3;
      }
      else if (block == 2){
          buff[7] = buff[7] |  B2B7C1;
          buff[8] = buff[8] & ~B2B8C2;
          buff[8] = buff[8] |  B2B8C3;
      }
      else if (block == 3){
          buff[7] = buff[7] |  TB7C1;
          buff[8] = buff[8] & ~TB8C2;
          buff[8] = buff[8] |  TB8C3;
      }
      break;
    case 0x36:
      if (block == 0) {
          buff[7] = buff[7] |  B0B7C1;
          buff[8] = buff[8] |  B0B8C2;
          buff[8] = buff[8] & ~B0B8C3;
      }
      else if (block == 1){
          buff[7] = buff[7] |  B1B7C1;
          buff[8] = buff[8] |  B1B8C2;
          buff[8] = buff[8] & ~B1B8C3;
      }
      else if (block == 2){
          buff[7] = buff[7] |  B2B7C1;
          buff[8] = buff[8] |  B2B8C2;
          buff[8] = buff[8] & ~B2B8C3;
      }
      else if (block == 3){
          buff[7] = buff[7] |  TB7C1;
          buff[8] = buff[8] |  TB8C2;
          buff[8] = buff[8] & ~TB8C3;
      }
      break;
    case 0x37:
      if (block == 0) {
          buff[7] = buff[7] | B0B7C1;
          buff[8] = buff[8] | B0B8C2;
          buff[8] = buff[8] | B0B8C3;
      }
      else if (block == 1){
          buff[7] = buff[7] | B1B7C1;
          buff[8] = buff[8] | B1B8C2;
          buff[8] = buff[8] | B1B8C3;
      }
      else if (block == 2){
          buff[7] = buff[7] | B2B7C1;
          buff[8] = buff[8] | B2B8C2;
          buff[8] = buff[8] | B2B8C3;
      }
      else if (block == 3){
          buff[7] = buff[7] | TB7C1;
          buff[8] = buff[8] | TB8C2;
          buff[8] = buff[8] | TB8C3;
      }
      break;
  }

  // calc inverted in BUF 6 and 7
  buff[6] = buff[7] >> 4;             // C1
  buff[6] = buff[6] | (buff[8] << 4); // C2
  buff[6] = ~buff[6];                 // invert

  buff[7] = buff[7] & 0xf0;
  buff[7] = buff[7] | ((~buff[8] >> 4) & 0x0f);   //~c3
}


/* get block number
 * check whether a valid was provided on the command line with -B option
 * blocks : maximum blocknunber
 * chk_trail : check for trailer (1) or not (0)
 */

int get_block_number(int blocks, int chk_trail)
{
	int blocknr;

	do
	{
		// was provided on the command line ?
		if (use_vblock != 0xff)
		{
			blocknr = use_vblock;
			p_printf(GREEN,"%d\n", blocknr);
		}

		else
		{
			blocknr = get_number();
		}

        if (blocknr == 0)  return(0);

		if (blocknr > blocks)
		{
			p_printf(RED,"Block number is to high %2d. Maximum %d\n",blocknr, blocks);
			blocknr = -1;
		}

		else if (blocknr < 0)
		{
			p_printf(RED,"Block can't be below 0.\n");
			blocknr = -1;
		}

        // check for trailer ?
		else if (chk_trail)
		{
			if ((blocknr == 3) || (! ((blocknr-3) % 4)))
			{
				p_printf(RED,"Can not use a trailer location.\n");
				blocknr = -1;
			}
		}

		if (blocknr == -1)
		{
			p_printf(YELLOW,"Try again\n");
			use_vblock = 0xff; // reset potential command line provided block
		}

	} while (blocknr == -1);

	return(blocknr);
}

/* get single digital number */
int	get_number()
{
	int 	num,ch;

	scanf("%d", &num);
	
    // flush any input pending
    while ((ch=getchar()) != '\n' && ch != EOF);
    
    return(num);
}

/* get single (uppercase) character */
char	get_charc()
{
	char 	charc; 
	int		ch;
	
	scanf("%c", &charc);

    // flush any input pending
    while ((ch=getchar()) != '\n' && ch != EOF);
    
    return(toupper(charc));
}

/* get string 
 * buf : ponter to store string
 * len : maximum len of string
 */
void	get_str(char * buf, int len)
{
	// clear memory
	memset(buf,0,len);
	
	// get input
	fgets(buf, len, stdin);

	// terminate with 0 instead of \n
	buf[strlen(buf) -1 ] = 0;
}
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
int main() {
  
    int pass = 0; // Pass no Pass
  
    // must be run as root to open /dev/mem in BMC2835
    if (getuid() != 0)
    {
        p_printf(RED,"Must be run as root.\n");
        exit(1);
    }
  
    Led_On();

    // catch signals
	set_signals();
	  
    // read /etc/rc522.conf 
    if (get_config_file()) exit(1);

    // set BCM2835 Pins correct
    if (HW_init(spi_speed,gpio)) close_out(1);
  
    // initialise the RC522
	InitRc522();

    // read & set GID and UID from config file
    if (read_conf_uid()!= 0) close_out(1);


    digitalWrite(3, LOW);	
    while (loop > 0)
    {
	char *card_no;
	card_no = send_card_no();
	printf("Message recieved: %s\n", card_no); 
	// count this card
        if (NotEndless)    loop--;
      
        use_vblock = 0xff;

        // close / disconnect the card
        PcdHalt();        

	int Led_Pin = 0;
	printf("CARD: %s\n",card_str);
	pass = user_access(card_str);
	//pass = 0;
	if (pass){
	  Led_Pin = 4;
          printf("Green!: %d\n", pass);
	  digitalWrite(Led_Pin, HIGH);
  	  bcm2835_delay(1500);
	  digitalWrite(Led_Pin, LOW);
          //Buzz_Once();
        }
        else{
	  Led_Pin = 3;
          printf("Red!: %d\n", pass);
	  digitalWrite(Led_Pin, HIGH);
  	  bcm2835_delay(1500);
	  digitalWrite(Led_Pin, LOW);
          //Buzz_Twice();
        }
        printf("OUT");
       
        p_printf(YELLOW,"Please remove card within 5 seconds\n");
            
        sleep(5);
        
    }   // loop

    return 0;
}*/

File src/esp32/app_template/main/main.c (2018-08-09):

/**
 * @brief Template for the EPL RFID project
 *
 *
 *
 */

#include "freertos/FreeRTOS.h"
#include "esp_wifi.h"
#include "esp_system.h"
#include "esp_event.h"
#include "esp_event_loop.h"
#include "nvs_flash.h"
#include "driver/gpio.h"

esp_err_t event_handler(void *ctx, system_event_t *event)
{
  return ESP_OK;
}

void app_main(void)
{
  nvs_flash_init();
  tcpip_adapter_init();
  ESP_ERROR_CHECK( esp_event_loop_init(event_handler, NULL) );
  wifi_init_config_t cfg = WIFI_INIT_CONFIG_DEFAULT();
  ESP_ERROR_CHECK( esp_wifi_init(&cfg) );
  ESP_ERROR_CHECK( esp_wifi_set_storage(WIFI_STORAGE_RAM) );
  ESP_ERROR_CHECK( esp_wifi_set_mode(WIFI_MODE_STA) );
  wifi_config_t sta_config = {
    .sta = {
      .ssid = "access_point_name",
      .password = "password",
      .bssid_set = false
    }
  };
  ESP_ERROR_CHECK( esp_wifi_set_config(WIFI_IF_STA, &sta_config) );
  ESP_ERROR_CHECK( esp_wifi_start() );
  ESP_ERROR_CHECK( esp_wifi_connect() );

  gpio_set_direction(GPIO_NUM_4, GPIO_MODE_OUTPUT);
  int level = 0;
  while (true) {
    gpio_set_level(GPIO_NUM_4, level);
    level = !level;
    vTaskDelay(300 / portTICK_PERIOD_MS);
  }
}

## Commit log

2018-07-03 Initial copy from previous repos
    Here are links to the previous repos:
    LUCCA:
    Repo: https://github.com/LUCCA-Capstone/LUCCA
    Wiki: https://github.com/LUCCA-Capstone/LUCCA/wiki
    EPL RFID:
    Repo: https://github.com/Crimson89/RFID-Capstone
    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
    [Materials.xlsx, reader_v1.brd, reader_v1.sch]
2018-08-04 starting work on the esp32. it flashes properly
2018-08-04 switched to branch dev_chad_esp32
2018-08-29 Add files via upload
    Rev 1 of attempt to layout MiFare MFRC 522 13.56MHz reader
    [RFID MFRC522.brd, RFID MFRC522.sch]
2018-11-13 moved v2 board to RFID
    [RFID_reader_v2.brd, RFID_reader_v2.sch]

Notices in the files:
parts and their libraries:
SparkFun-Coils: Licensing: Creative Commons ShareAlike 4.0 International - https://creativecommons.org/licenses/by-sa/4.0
